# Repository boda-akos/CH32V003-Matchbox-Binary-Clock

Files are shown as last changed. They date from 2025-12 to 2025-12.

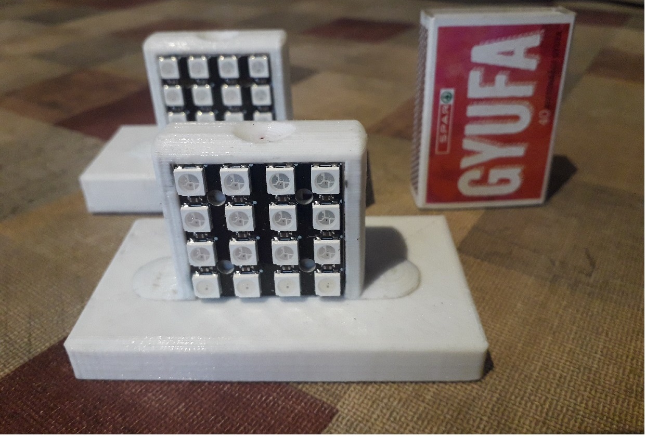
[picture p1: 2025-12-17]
20251217_090148.jpg

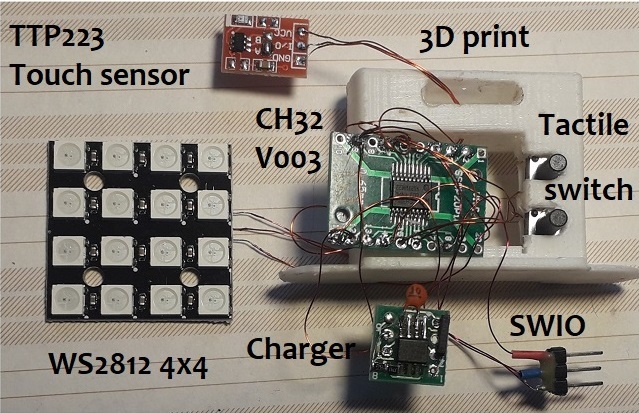
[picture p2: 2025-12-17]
20251216_111504.jpg

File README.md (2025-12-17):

# CH32V003-Matchbox-Binary-Clock
CH32V003 PCF8563 WS2812B learning project.
Clock in matchbox size with touch control

Binary clock, it has 16 pieces WS2812B arranged in a 4x4 matrix display showing binary coded time.

Touching the top, the CH32V003 gets a wake up interrupt from a TTP223 touch sensor, wakes from sleep, reads the RTC chip PCF8563 and displays the time on WS2812 chain. Waits 2 sec, turns off the WS2812 supply and goes back to sleep mode to save the battery. In this mode, the consumption is about 20 uA, it means that the battery is good for 30000 working hours (many years theoretically) with a single charge.

The color of the WS2812 is freely adjustable in the Arduino program, the default is red for the 1, yellow for 2, green 4, blue (purple) 8 binary weight. To read the time, you add the weights vertically. 

Display: The matrix of 16 WS2812B LEDs in series is available on Aliexpress. Connect 3 wires, Gnd, Vcc, DI data. The 470uF capacitor smoothes current peaks. Position the display with the solder pads up.

CH32V003 module : CH32V003F4P6 chip soldered on a 20 pin adapter PCB, the module runs on 24Mhz internal clock. The Vcc GND pin has 100nF + 470uF capacitors soldered on. Use the WCH-LinkE interface for programming, you need 3 wires : Vcc, 3V3, and SWIO on pin PD1. Unlike the AVR Arduinos, this chip needs no bootloader.

TTP223 :  Make the A jumper (active low output). Remove the LED or its resistor. Use no pins, the space is limited.
Available here: https://www.aliexpress.com

PCF8563 clock module : built on a SOP8 PCB, the module is very small.

TP4056 : Remove/replace the 1k2 resistor with 6k8.  Order the smallest possible TP4056 module. Use no pins, the space is limited.
Available here: https://www.aliexpress.com

Construction : Print the 3D parts. Use 0.25mm enamel wire for wiring. The WS matrix is followed by the CH32 board and the clock board in the case. There is a cavity for the TTP223 and the 6x6mm tactile switches. See picture.  
    
The battery compartment is made for a 37x50x7mm battery in this design. You may use any other type of Li-Ion battery, 3D print a box for it using my wedge assembly or simply glue it to the clock case. Drill or burn a hole for the wires to the Arduino.

What I learned from this project : using direct register control, mixing MounRiver Studio code into Arduino (it works), powersave mode which uses only 10-20 uA current, pin interrupt, driving the WS2812B without libraries. Avoid Arduino pinMode() instructions, drives powersave current up to 100uA. The instruction like GPIOC->OUTDR &= ~(1 << 3); executes faster than the MounRiver style GPIO control, like  GPIO_WriteBit(GPIOC, GPIO_Pin_3, Bit_RESET) and waaaay faster than digitalWrite().

See the old Arduino AVR version here https://www.thingiverse.com/thing:6302260

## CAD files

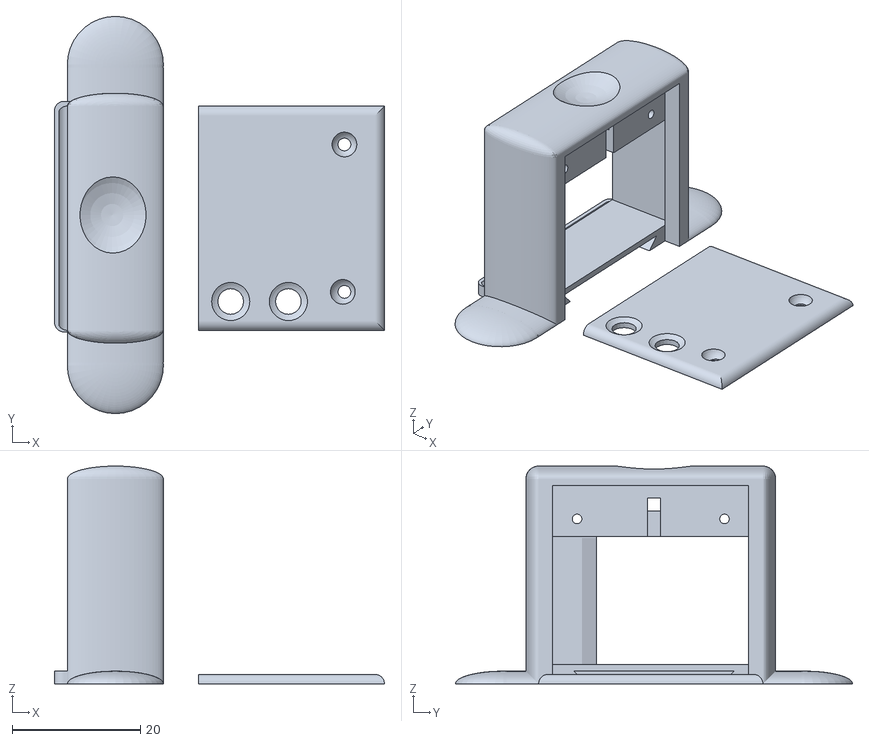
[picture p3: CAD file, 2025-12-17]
tabClkMain.stl
51.5 x 62.0 x 34.0

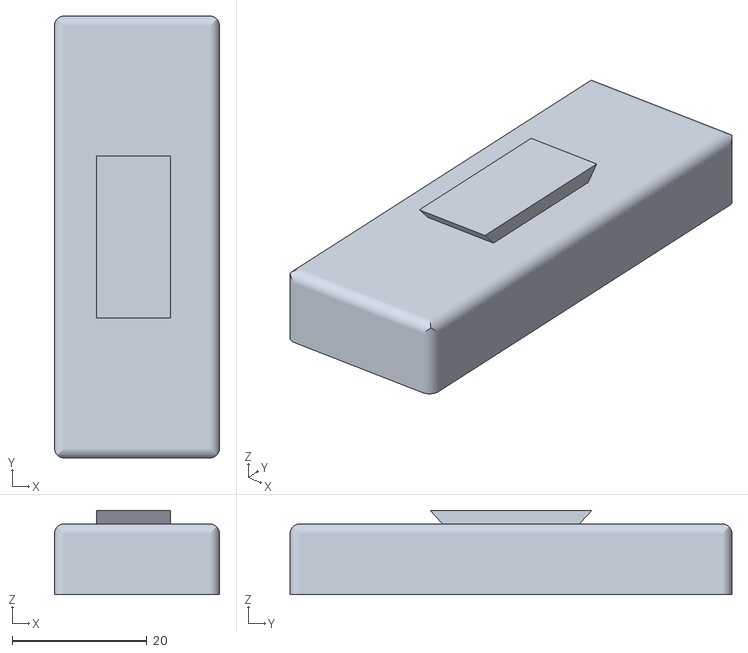
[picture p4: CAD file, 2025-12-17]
Battery1.stl
24.5 x 65.5 x 12.5

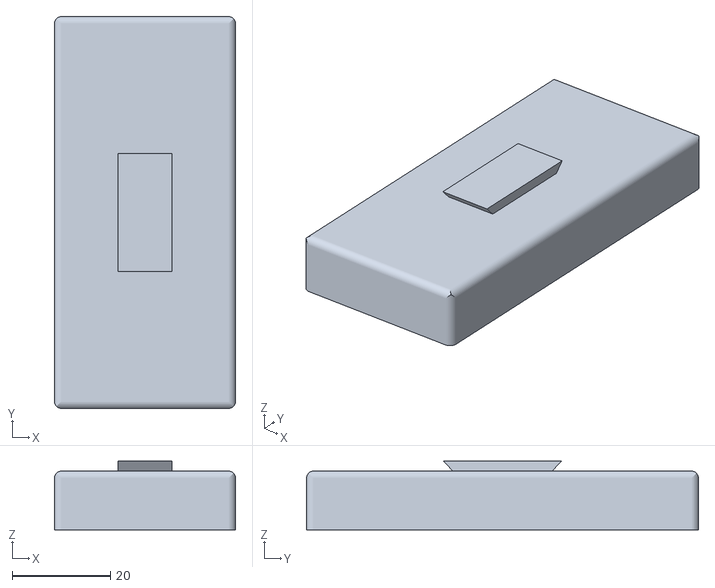
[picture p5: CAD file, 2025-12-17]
Battery2.stl
37.0 x 80.0 x 14.0

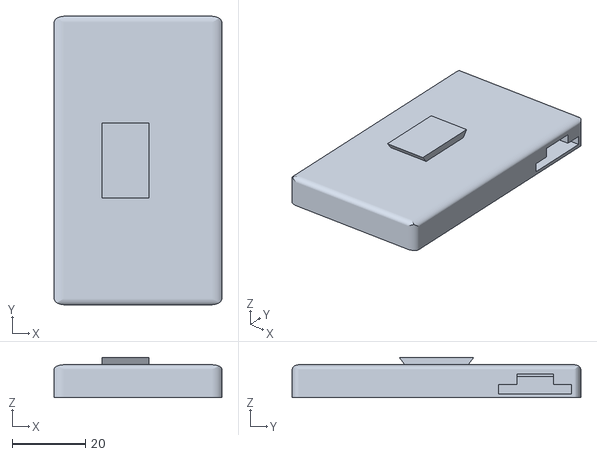
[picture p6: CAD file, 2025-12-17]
tabClkBat.stl
46.0 x 79.0 x 11.0

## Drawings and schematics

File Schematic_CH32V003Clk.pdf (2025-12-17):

## Reset (optional) Replace resistor 1k2

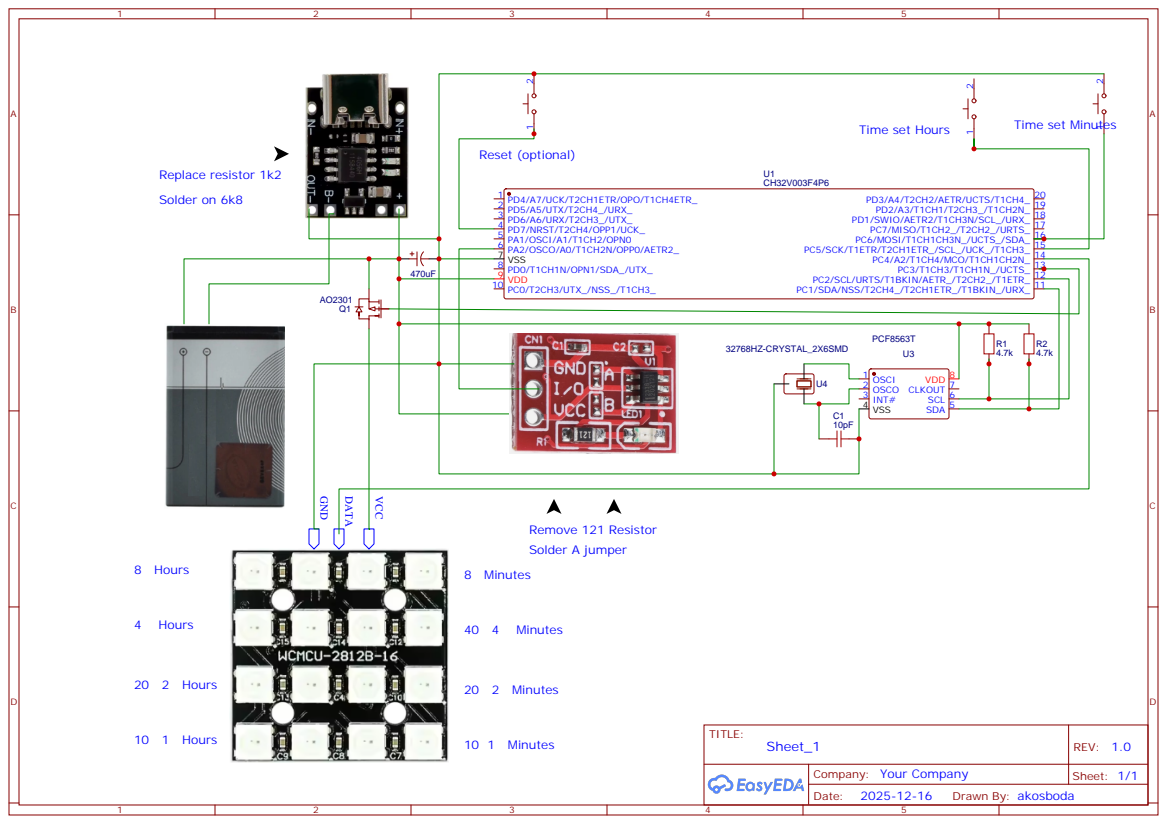
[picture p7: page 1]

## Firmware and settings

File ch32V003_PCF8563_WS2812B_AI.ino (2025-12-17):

// This setup runs on 24Mhz internal clock only - power save requirement
// PMOS AO3401 power switch to WS2812B + supply, 16 LED matrix , see arrangement 
//       8   0
//       9 6 1
//   13 10 5 2
//   12 11 4 3

// PCF8563 clock chip + 32768Hz crystal
// Li Ion battery, charger TP4056, 1k2 resistor -> 6k8 reduced charge current
// TTP223 touch sensor to pin PA2
// LED power to pin PC3 

#define led_num 16

typedef struct {
    byte r;  // Red component (0-255)
    byte g;  // Green component (0-255)
    byte b;  // Blue component (0-255)
} WS_Color;

// Pre-defined colors
#define WS_RED (WS_Color){255, 0, 0}
#define WS_GREEN (WS_Color){0, 255, 0}
#define WS_BLUE (WS_Color){0, 0, 255}
#define WS_WHITE (WS_Color){255, 255, 255}
#define WS_BLACK (WS_Color){0, 0, 0}
#define WS_PURPLE (WS_Color){128, 0, 128}
#define WS_YELLOW (WS_Color){255, 255, 0}
#define WS_CYAN (WS_Color){0, 255, 255}
#define WS_ORANGE (WS_Color){255, 165, 0}
#define WS_PINK (WS_Color){255, 20, 147}

void WS_SetBrightness(byte brightness);
void WS_SetPixel(byte index, WS_Color color);
void WS_Fill(WS_Color color);
void WS_Clear(void);
void WS_Show(void);

WS_Color WS_RGB(byte r, byte g, byte b);
static WS_Color led_buffer[16];

byte a = 8;  // intensity

// PCF8523:  SDA pin 5 -> to PC1 pin 11
//           SCL pin 6 -> to PC2 12
 // LED VCC PC3 via PMOS  Data PC4

#include "Wire.h"
#define PCF8563address 0x51

byte second, minute, hour, dayOfWeek, dayOfMonth, month, year;

void setup() {
    //Serial.begin(115200); Serial.setTimeout(1);
    
    // change the following to set your initial time
    second = 00;
    minute = 0x32;
    hour = 0x14;
    dayOfWeek = 4;
    dayOfMonth = 14;
    month = 11;
    year = 25;

    //This GPIO configuration became part of GPIOConfig
    //pinMode(PC3, OUTPUT); pinMode(PC4, OUTPUT); // LED power and data
    //while(1) {GPIOC->OUTDR |=(1<<3); delay(1); GPIOC->OUTDR &=~(1<<3); delay(1);}

    // pinMode(PC1, INPUT_PULLUP); pinMode(PC2, INPUT_PULLUP);  // i2c to PCF8263
    // pinMode(PC5, INPUT_PULLUP); pinMode(PC6, INPUT_PULLUP);
    
    GPIOConfig();
    NVIC_PriorityGroupConfig(NVIC_PriorityGroup_1);
    SystemCoreClockUpdate(); 

    EXTI2_INT_INIT();
  
    Wire.begin(); 
    
    // comment out the next line and upload again to set and keep the time from resetting 
    //setPCF8563();
      GPIOC->OUTDR &= ~(1 << 3); 

    // Initialize all pixels just to see 
   //  colorWipe(WS_RED); colorWipe(WS_GREEN);colorWipe(WS_BLUE);
}

void loop() {  
    readPCF8563();
    GPIOC->OUTDR &= ~(1 << 3);  //turn LED power on
    delay(10);
    led();
   
    // =============== Adjusting time =================
    // Pullup input PC5 and PC6 pin is connected to tactile switches 
    bool adjusted = false;
    
    while (digitalRead(PC5) == 0) {
        hour++; 
        if ((hour & 0x0f) == 0x0a) hour += 6;  
        if (hour > 0x23) hour = 0;
        led();
        delay(500); 
        adjusted = true;
    } // adjust hours
    
    while (digitalRead(PC6) == 0) {
        minute++; 
        if ((minute & 0x0f) == 0x0a) minute += 6;  
        if (minute > 0x59) minute = 0;
        led();
        delay(500); 
        adjusted = true;
    } // adjust minutes
    
    if (adjusted) {       // ============ writing to RTC ========
        setPCF8563();
    }
    
    delay(1000);
    GPIOC->OUTDR |= (1 << 3);  
    PWR_EnterSTANDBYMode(PWR_STANDBYEntry_WFE);
    // Reset follows after interrupt on PA2
}

void led(void) {   // displays global variables second, minute, hour
    for (byte i = 0; i < 16; i++) 
        WS_SetPixel(i, WS_BLACK); 
    
    // minute
    if (minute & 1)  WS_SetPixel(3, WS_RED);    // red WS_SetPixel(5, WS_ORANGE);
    if (minute & 2)  WS_SetPixel(2, WS_YELLOW); // yellow
    if (minute & 4)  WS_SetPixel(1, WS_GREEN);  // green
    if (minute & 8)  WS_SetPixel(0, WS_PURPLE); // magenta
    
    // 10 minute
    if (minute & 0x10)  WS_SetPixel(4, WS_RED);
    if (minute & 0x20)  WS_SetPixel(5, WS_YELLOW);
    if (minute & 0x40)  WS_SetPixel(6, WS_GREEN);
    
    // hour
    if (hour & 1)   WS_SetPixel(11, WS_RED);
    if (hour & 2)   WS_SetPixel(10, WS_YELLOW);
    if (hour & 4)   WS_SetPixel(9, WS_GREEN);
    if (hour & 8)   WS_SetPixel(8, WS_PURPLE);
    
    // 10 hour
    if (hour & 0x10) WS_SetPixel(12, WS_RED);
    if (hour & 0x20) WS_SetPixel(13, WS_YELLOW);

    WS_Show(); 
    delay(100);
}

// Fill the dots one after the other with a color
void colorWipe(WS_Color color) {
    for (uint16_t i = 0; i < 16; i++) {
        WS_SetPixel(i, color);
        WS_Show();
        delay(100);
    }
}

void GPIOConfig() {
    GPIO_InitTypeDef GPIO_InitStructure = {0};
    RCC_APB2PeriphClockCmd(RCC_APB2Periph_GPIOA | RCC_APB2Periph_GPIOC | RCC_APB2Periph_GPIOD, ENABLE);
    RCC_APB1PeriphClockCmd(RCC_APB1Periph_PWR, ENABLE);
    
    GPIO_InitStructure.GPIO_Pin = GPIO_Pin_All; 
    GPIO_InitStructure.GPIO_Mode = GPIO_Mode_IPU; 
    GPIO_Init(GPIOA, &GPIO_InitStructure);
    GPIO_Init(GPIOC, &GPIO_InitStructure);
    GPIO_Init(GPIOD, &GPIO_InitStructure);

    GPIO_InitStructure.GPIO_Pin = GPIO_Pin_3 | GPIO_Pin_4; // 0b00011000 GPIOC
    GPIO_InitStructure.GPIO_Mode = GPIO_Mode_Out_PP; 
    GPIO_InitStructure.GPIO_Speed = GPIO_Speed_2MHz; 
    GPIO_Init(GPIOC, &GPIO_InitStructure);     
}

void EXTI2_INT_INIT(void) {
    EXTI_InitTypeDef EXTI_InitStructure = {0};
    NVIC_InitTypeDef NVIC_InitStructure = {0};

    RCC_APB2PeriphClockCmd(RCC_APB2Periph_AFIO | RCC_APB2Periph_GPIOA, ENABLE);
    GPIO_EXTILineConfig(GPIO_PortSourceGPIOA, GPIO_PinSource2); 
    
    EXTI_InitStructure.EXTI_Line = EXTI_Line2;
    EXTI_InitStructure.EXTI_Mode = EXTI_Mode_Interrupt;
    EXTI_InitStructure.EXTI_Trigger = EXTI_Trigger_Falling;
    EXTI_InitStructure.EXTI_LineCmd = ENABLE;
    EXTI_Init(&EXTI_InitStructure);

    NVIC_InitStructure.NVIC_IRQChannel = EXTI7_0_IRQn;
    NVIC_InitStructure.NVIC_IRQChannelPreemptionPriority = 0;
    NVIC_InitStructure.NVIC_IRQChannelSubPriority = 1;
    NVIC_InitStructure.NVIC_IRQChannelCmd = ENABLE;
    NVIC_Init(&NVIC_InitStructure);
}

void EXTI7_0_IRQHandler(void) __attribute__((interrupt("WCH-Interrupt-fast")));

void EXTI7_0_IRQHandler(void) {
    if (EXTI_GetITStatus(EXTI_Line2) != RESET) {
        EXTI_ClearITPendingBit(EXTI_Line2);
    }
}

byte bcdToDec(byte value) {
    return ((value / 16) * 10 + value % 16);
}

byte decToBcd(byte value) {
    return (value / 10 * 16 + value % 10);
}

void setPCF8563() {
    // this sets the time and date to the PCF8563
    Wire.beginTransmission(PCF8563address);
    Wire.write(0x02);  
    Wire.write(second);  
    Wire.write(minute);
    Wire.write(hour);     
    Wire.write(dayOfMonth);
    Wire.write(dayOfWeek);  
    Wire.write(month);
    Wire.write(year);
    Wire.endTransmission();
    GPIOC->OUTDR &= ~(1 << 3); // LED power on
}

void readPCF8563() {
    // this gets the time and date from the PCF8563
    Wire.beginTransmission(PCF8563address);
    Wire.write(0x02);
    Wire.endTransmission();
    Wire.requestFrom(PCF8563address, 3);
    second = Wire.read() & 0x7f; // remove VL error bit
    minute = Wire.read() & 0x7f; //
    hour   = Wire.read() & 0x3f; 
    // dayOfMonth = bcdToDec(Wire.read() & B00111111);
    // dayOfWeek  = bcdToDec(Wire.read() & B00000111);  
    // month      = bcdToDec(Wire.read() & B00011111);  // remove century bit, 1999 is over
    // year       = bcdToDec(Wire.read());
}

void wakeUp() {
    // Handler for the pin interrupt.
}

static void send_bit(byte x) { // this setup runs on 24Mhz internal clock, commented out section 48Mhz clock
    if (x) { // Send a 1 bit (high for 0.8us, low for 0.45us, tolerance 150usec)
        GPIOC->OUTDR |= (1 << 4);  // Set high
        __asm__ volatile ("nop"); __asm__ volatile ("nop"); __asm__ volatile ("nop"); __asm__ volatile ("nop"); __asm__ volatile ("nop"); __asm__ volatile ("nop"); 
        __asm__ volatile ("nop"); __asm__ volatile ("nop"); __asm__ volatile ("nop"); __asm__ volatile ("nop"); __asm__ volatile ("nop"); __asm__ volatile ("nop"); 
        __asm__ volatile ("nop"); __asm__ volatile ("nop"); /* __asm__ volatile ("nop"); __asm__ volatile ("nop"); __asm__ volatile ("nop"); __asm__ volatile ("nop"); 
        __asm__ volatile ("nop"); __asm__ volatile ("nop"); __asm__ volatile ("nop"); __asm__ volatile ("nop"); __asm__ volatile ("nop"); __asm__ volatile ("nop"); 
        __asm__ volatile ("nop"); __asm__ volatile ("nop"); __asm__ volatile ("nop"); __asm__ volatile ("nop"); __asm__ volatile ("nop"); __asm__ volatile ("nop");
        __asm__ volatile ("nop"); __asm__ volatile ("nop"); __asm__ volatile ("nop"); */
        
        GPIOC->OUTDR &= ~(1 << 4);    // Set low 
        __asm__ volatile ("nop"); __asm__ volatile ("nop"); __asm__ volatile ("nop"); __asm__ volatile ("nop"); __asm__ volatile ("nop"); /*__asm__ volatile ("nop"); 
        __asm__ volatile ("nop"); __asm__ volatile ("nop"); __asm__ volatile ("nop"); __asm__ volatile ("nop"); __asm__ volatile ("nop"); __asm__ volatile ("nop"); 
        __asm__ volatile ("nop"); __asm__ volatile ("nop"); __asm__ volatile ("nop"); */
    } else { // Send a 0 bit (high for 0.4us, low for 0.85us, tolerance 150usec)
        GPIOC->OUTDR |= (1 << 4);   
        __asm__ volatile ("nop"); __asm__ volatile ("nop"); __asm__ volatile ("nop"); /*__asm__ volatile ("nop"); __asm__ volatile ("nop"); __asm__ volatile ("nop"); 
        __asm__ volatile ("nop"); __asm__ volatile ("nop"); __asm__ volatile ("nop"); __asm__ volatile ("nop"); __asm__ volatile ("nop"); __asm__ volatile ("nop");*/ 
        
        GPIOC->OUTDR &= ~(1 << 4);  // Set low
        __asm__ volatile ("nop"); __asm__ volatile ("nop"); __asm__ volatile ("nop"); __asm__ volatile ("nop"); __asm__ volatile ("nop"); __asm__ volatile ("nop"); 
        __asm__ volatile ("nop"); __asm__ volatile ("nop"); __asm__ volatile ("nop"); __asm__ volatile ("nop"); __asm__ volatile ("nop"); /*__asm__ volatile ("nop"); 
        __asm__ volatile ("nop"); __asm__ volatile ("nop"); __asm__ volatile ("nop"); __asm__ volatile ("nop"); __asm__ volatile ("nop"); __asm__ volatile ("nop"); 
        __asm__ volatile ("nop"); __asm__ volatile ("nop"); __asm__ volatile ("nop"); __asm__ volatile ("nop"); __asm__ volatile ("nop"); __asm__ volatile ("nop"); 
        __asm__ volatile ("nop"); __asm__ volatile ("nop"); __asm__ volatile ("nop"); __asm__ volatile ("nop"); */ 
    }  
    //GPIOC->OUTDR |=(1<<4); GPIOC->OUTDR &=~(1<<4); //Marker for oscilloscope waveform check
}

// Send a byte to WS2812B
static void send_byte(byte b) {
    for (byte x = 0x80; x > 0; x /= 2) 
        send_bit(b & x);
}

// Send array data to LED strip
void WS_Show(void) {
    // a should be 0-32 for 32 brightness levels
    for (byte i = 0; i < 16; i++) {
        // Multiply then shift right 5 bits (divide by 32)
        int scaled_g = (led_buffer[i].g * a) >> 5;
        int scaled_r = (led_buffer[i].r * a) >> 5;
        int scaled_b = (led_buffer[i].b * a) >> 5;
        
        send_byte(scaled_g);
        send_byte(scaled_r);
        send_byte(scaled_b);
    }  
    //GPIOC->OUTDR &=~(1<<4);  // exit with Data pin=Low
    delayMicroseconds(100);  // Reset pulse delay >50us 
}

// Fill all LEDs with the same color
void WS_Fill(WS_Color color) {
    for (byte i = 0; i < 16; i++) {
        led_buffer[i] = color;
    }
}

// Set pixel color 
void WS_SetPixel(byte index, WS_Color color) {
    led_buffer[index] = color;
}

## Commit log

2025-12-17 Update project learnings in README.md
    Expanded on learnings from the project regarding direct register control and power-saving techniques.
2025-12-17 Reference in README
    Added a reference to the old Arduino AVR version for users seeking additional resources.
